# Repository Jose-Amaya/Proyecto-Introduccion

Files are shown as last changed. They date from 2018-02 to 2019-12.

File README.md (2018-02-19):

# Proyecto Introducción a la Ingeniería: Información sobre centrales de generación en Colombia

El proyecto consiste, en una estructura con un mapa de Colombia, el cuál tiene en cada punto donde hay una de las 47 centrales escogidas, un LED, el cuál estará encendido si la central en ese punto se encuentra en funcionamiento, y apagado si la central no está en funcionamiento, el color del LED depende del tipo de generación que se da en la central, y además hay un panel en donde se muestra la información de generación para cada central.

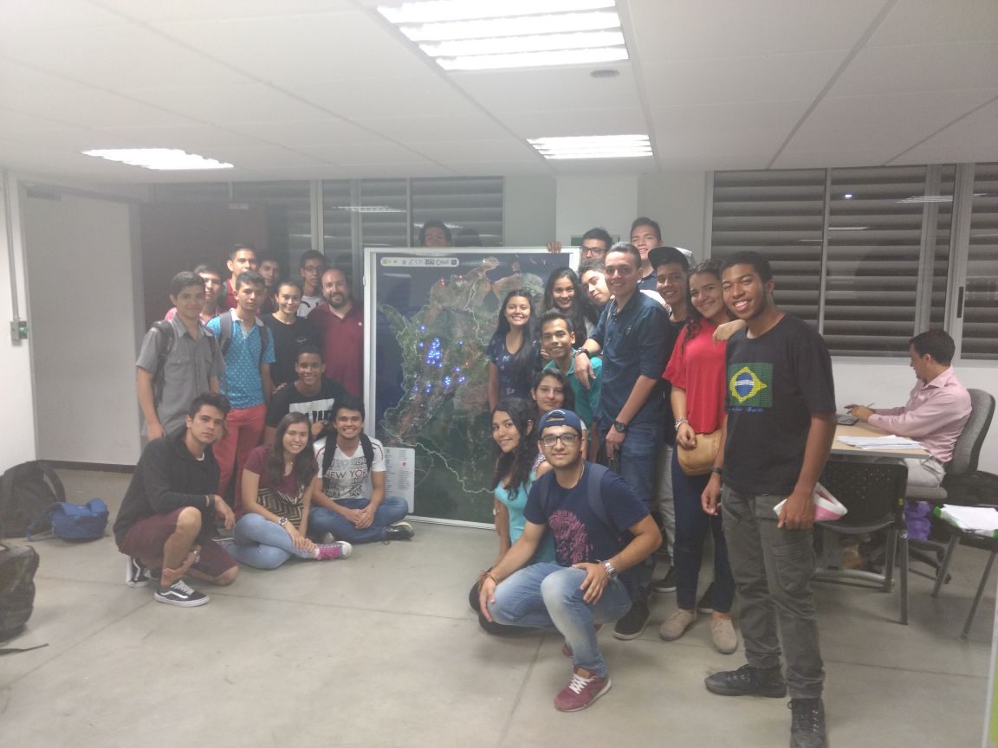
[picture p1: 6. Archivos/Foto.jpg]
Grupo Del Proyecto


# Partes del proyecto

Para el desarrollo del proyecto:
1. Se editó el mapa para agregar la ubicacion de cada central, y las convenciones. [Abrir Carpeta](1.%20Diseño%20mapa/)
2. Se creó un programa en python que corre en una [Raspberri pi 3](https://www.raspberrypi.org/products/raspberry-pi-3-model-b/). [Abrir Carpeta](2.%20Programación/)
3. Se diseño una PCB, para controlar los 47 LEDs, con solo 16 pines ( o menos ) de la raspberry pi ( Por medio de una matriz de LEDS ) [Abrir Carpeta](3.%20PCB/)
4. Se diseño una página web para mostrar los datos de generación de las centrales en un panel. [Abrir Carpeta](4.%20Página%20web/)
5. Se diseño una estructura para contener todos los elementos.
6. Se consiguio información sobre las centrales de xm.com.co [Abrir Archivo Centrales.xlsx](6.%20Archivos/Centrales.xlsx)

Visitar cada carpeta para obtener mas información

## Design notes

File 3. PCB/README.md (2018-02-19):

# Archivos

## Orden de conexion

### tarjetaCentrales

En el archivo se encuentra el diseño de la PCB, y en cada puerto se indica la central a la que corresponde

## PCB

### tarjetaPCB

El diseño de la PCB

### tarjetaSchematic

El esquema del circuito

## EAGLE

Archivos del diseño y esquema para el programa [EAGLE](https://www.autodesk.com/education/free-software/eagle) de Autodesk

## Raspberry Pi

### pi3gpio

Numeración de los pines GPIO de la Raspberry Pi 3

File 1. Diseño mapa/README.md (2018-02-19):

# Diseño del mapa

El mapa se editó en [Adobe Photoshop](https://www.adobe.com/la/products/photoshop.html), agregando iconos a cada punto donde se encontraba una central, y se agregaron convenciones con el listado de centrales

## [Mapa Original](https://correouisedu-my.sharepoint.com/:b:/g/personal/jose2170484_correo_uis_edu_co/EQX8aF4t30xKqxL7ubjEklsB62ActlVU1G1Fpb4uw0_HsA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)

## [Mapa con convenciones](https://correouisedu-my.sharepoint.com/:i:/g/personal/jose2170484_correo_uis_edu_co/EcvZU96U1txIq9gJoRtAlh0BLJq_x_HnzWpGNJGehfyIjA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)

## [Convenciones](https://correouisedu-my.sharepoint.com/:i:/g/personal/jose2170484_correo_uis_edu_co/EULeLKLpBHtKiUwwDA0-71oBcbyABYgxnpovk3rnCAAioA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)

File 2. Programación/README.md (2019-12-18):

# Programación

Los archivos principales se encuentran en la carpeta "project", esta carpeta debe ir en el directorio 'home/pi' de la Raspberry Pi

Se planean utilizar los datos de Despacho Nacional, pero si es necesario, se pueden utilizar los datos de Oferta inicial, para esto se cambia una linea de código en matS.py

# Funcionamiento

Cada script ( *.py ) se encuentra comentado, explicando el funcionamiento de manera detallada

# Requisitos

Una memoria SD, de al menos 8GB, y preferiblemente de clase 10, para el sistema operativo

Para correr los programas en la Raspberry pi 3, Se necesita el sistema operativo [Raspbian (version Jessie)](https://www.raspberrypi.org/downloads/raspbian/), se necesita de [Python3.5](https://www.python.org/downloads/release/python-353/), y tener la [librería Pycurl](http://pycurl.io/) instalada, y para la página web, se necesita del servidor HTTP [Apache](https://httpd.apache.org/download.cgi) y también se necesita del módulo de PHP para el servidor

1. Instalar Raspbian:
	1. Descargar [RASPBIAN STRETCH WITH DESKTOP](https://www.raspberrypi.org/downloads/raspbian/)
	2. Descargar [Etcher](https://etcher.io/)
	3. Seguir las instrucciones de la página de [Etcher](https://etcher.io/) para instalar el sistema operativo en la memoria SD

2. Instalar Python3.5:
	1. Abrir el terminal y ejecutar:
	```
	sudo apt-get install python3.5
	```

3. Instalar la librería Pycurl:
	1. Abrir el terminal y ejecutar:
	```
	sudo pip install pycurl
	```
	2. Si la ejecución falla, ejecutar:
	```
	sudo apt-get install python-pip
	```
		y ejecutar 3.1. denuevo

4. Instalar el servidor HTTP Apache:
	1. Abrir el terminal y ejecutar:
	```
	sudo apt-get install apache2 -y
	```

5. Instalar el módulo PHP:
	1. Abrir el terminal y ejecutar:
	```
	sudo apt-get install php libapache2-mod-php -y
	```

Guias de referencia:
* https://www.raspberrypi.org/documentation/remote-access/web-server/apache.md

## Ejecución

Se ejecutarán matS.py (que actualiza el estado de cada led), dataUpdater.py (que se encarga de correr las funciones para actualizar la información) y dataUpdaterO.py en paralelo. para configurar los programas para que corran al encender la Raspberry, se realizaron estos pasos:

1. Abrir el terminal y ejecutar:
```
sudo nano /lib/systemd/system/matS.service
```

2. Escribir:
```
 [Unit]
 Description=MatS
 After=multi-user.target

 [Service]
 Type=idle
 ExecStart=/usr/bin/python3.5 /home/pi/project/matS.py
 Restart=always
 RestartSec=5

 [Install]
 WantedBy=multi-user.target
```

3. Presionar en orden las teclas / combinaciones de teclas:
```
CTRL + X
Y
ENTER
```

4. Ejecutar:
```
sudo nano /lib/systemd/system/dataUpdater.service
```

5. Escribir:
```
 [Unit]
 Description=DataUpdater
 After=network.target

 [Service]
 Type=idle
 ExecStart=/usr/bin/python3.5 /home/pi/project/data/dataUpdater.py
 Restart=always
 RestartSec=5

 [Install]
 WantedBy=multi-user.target
```

6. Presionar en orden las teclas / combinaciones de teclas:
```
CTRL + X
Y
ENTER
```

7. Ejecutar:
```
sudo nano /lib/systemd/system/dataUpdaterO.service
```

8. Escribir:
```
 [Unit]
 Description=DataUpdaterO
 After=network.target

 [Service]
 Type=idle
 ExecStart=/usr/bin/python3.5 /home/pi/project/data/OfertaInicial(Alternativa)/dataUpdaterO.py
 Restart=always
 RestartSec=5

 [Install]
 WantedBy=multi-user.target
```

9. Presionar en orden las teclas / combinaciones de teclas:
```
CTRL + X
Y
ENTER
```

10. En el terminal ejecutar ( una linea a la vez ):
```
sudo chmod 644 /lib/systemd/system/matS.service
sudo chmod 644 /lib/systemd/system/dataUpdater.service
sudo chmod 644 /lib/systemd/system/dataUpdaterO.service

sudo systemctl daemon-reload

sudo systemctl enable matS.service
sudo systemctl enable dataUpdater.service
sudo systemctl enable dataUpdaterO.service

sudo reboot
```

Guias de referencia:
* https://www.dexterindustries.com/howto/run-a-program-on-your-raspberry-pi-at-startup/#systemd
* https://www.raspberrypi.org/documentation/linux/usage/systemd.md
* https://www.freedesktop.org/software/systemd/man/systemd.service.html

## Información de los archivos

## Project

Es la carpeta que va en /home/pi de la raspberry

### matS.py

Programa que actualiza la matriz de LEDs basado en los datos que se encuentran en ./data/files/matSdata.txt

### infoWeb.py

Programa con una función para actualizar el archivo ./data/files/infoWeb.txt; en cada linea se muestra la informacion de la central para la hora actual, el orden es el mismo que en el archivo Centrales.xlsx (E1, T1 -> T11, H1 -> H35)

### dataUpdater.py

Se encarga de correr las funciones de los diferentes programas en ./data , así se evita que dos programas traten de editar un archivo al mismo tiempo, este programa se corre en paralelo con matS.py

### dataTranslate.py

Se encarga de tomar la información descargada en ./files/downData.txt ; tiene diferentes funciones hechas para acceder mas facilmente a la informacion

## OfertaInicial(Alternativa)

Si se desean usar los datos de Oferta inicial, y no los de Despacho nacional, se corre, de esta carpeta dataUpdaterO.py, y se actualiza matS.py

# PATH

Al pasar a la raspberry pi la carpeta 'project', revisar en los archivos dataGet , dataTranslate , infoWeb y matS, la variable Path al inicio del programa, esta debe ser igual a la carpeta donde se encuentra la carpeta project

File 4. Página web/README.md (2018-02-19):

# Configuración

Para usar la página con el servidor Apache, se requiere reemplazar archivos:

1. Mover la carpeta html a /home/pi

2. Abrir el terminal y ejecutar:
```
sudo rm /var/www/html -r
sudo mv /home/pi/html /var/www
```
## Detalles

La página web usa [Bootstrap framework](https://getbootstrap.com/), las librerías de javascript [jQuery](https://jquery.com/) y [Popper](https://popper.js.org/), y [PHP](http://www.php.net/)

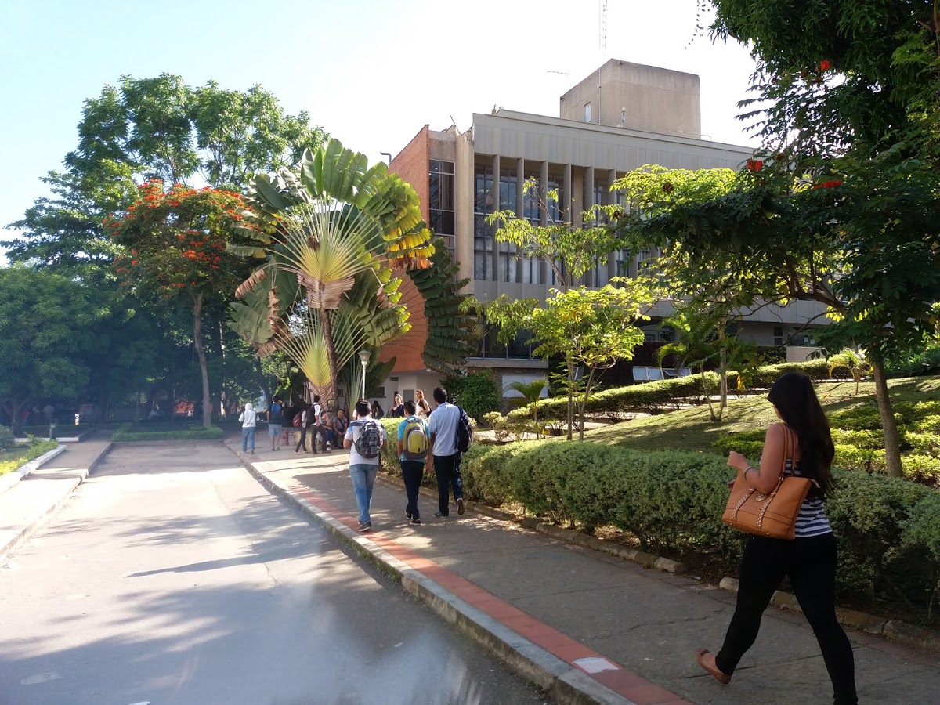
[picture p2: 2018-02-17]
4. Página web/html/img/biblio.jpg

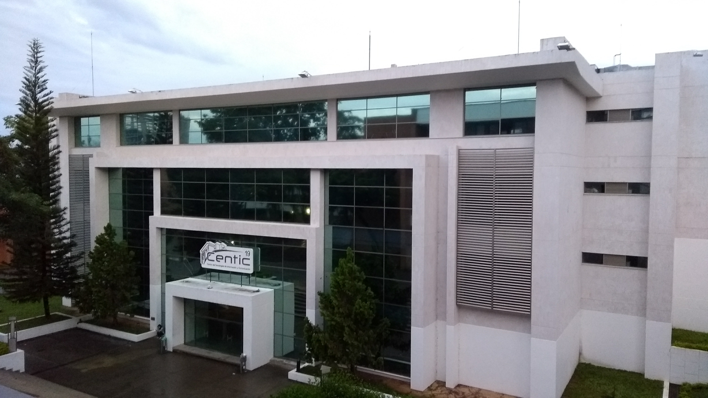
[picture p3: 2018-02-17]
4. Página web/html/img/centic.jpg

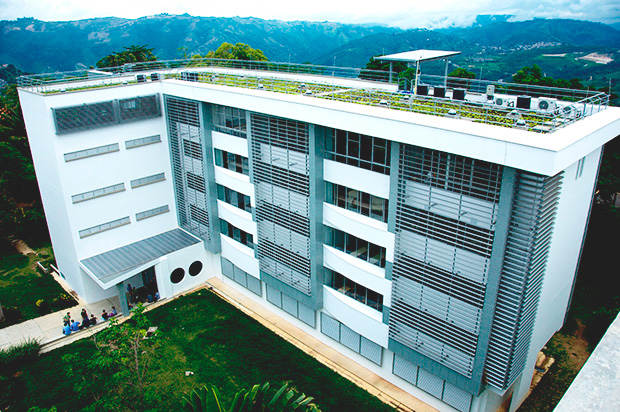
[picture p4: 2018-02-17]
4. Página web/html/img/e3t.jpg

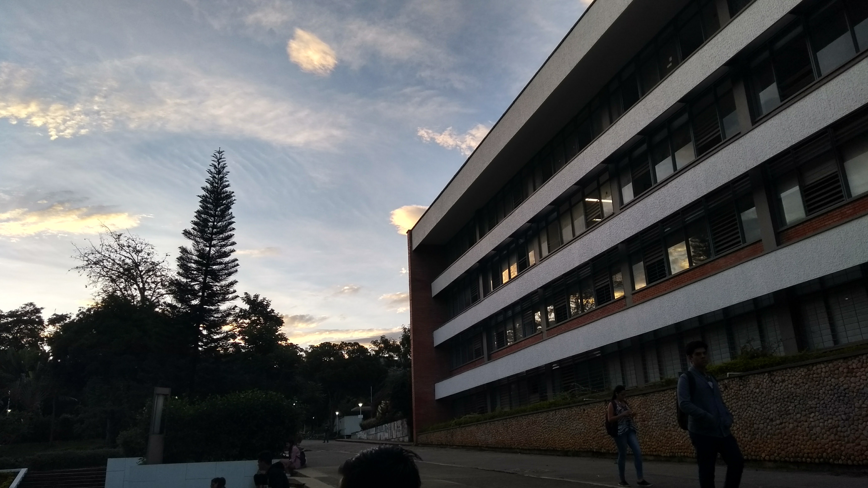
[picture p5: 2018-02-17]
4. Página web/html/img/ct.jpg

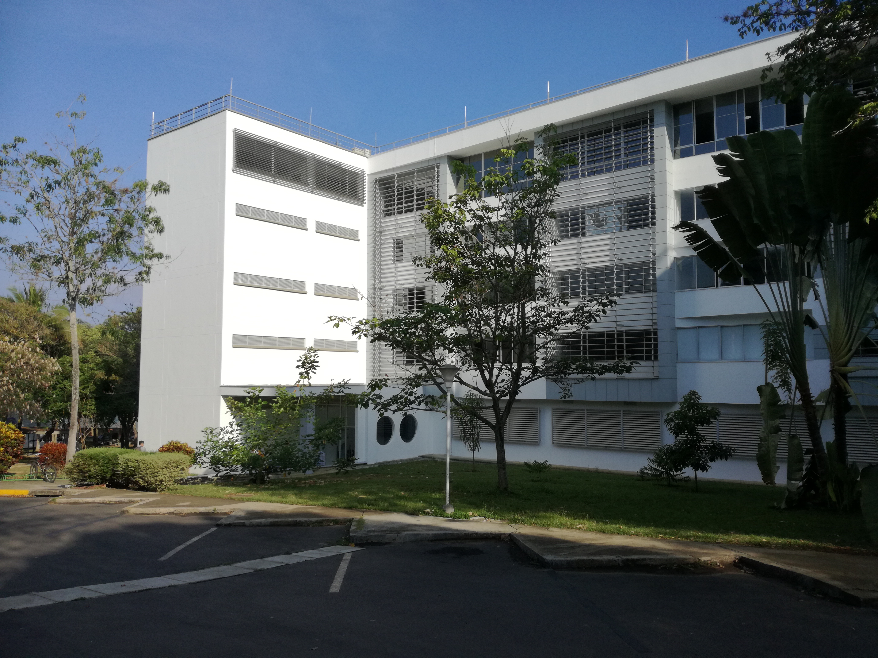
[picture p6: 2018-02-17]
4. Página web/html/img/e3t2.jpg

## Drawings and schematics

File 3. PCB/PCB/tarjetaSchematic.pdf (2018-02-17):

Q9

Q10 | Q11 | Q12 | Q13 | Q14 | Q15 | Q16

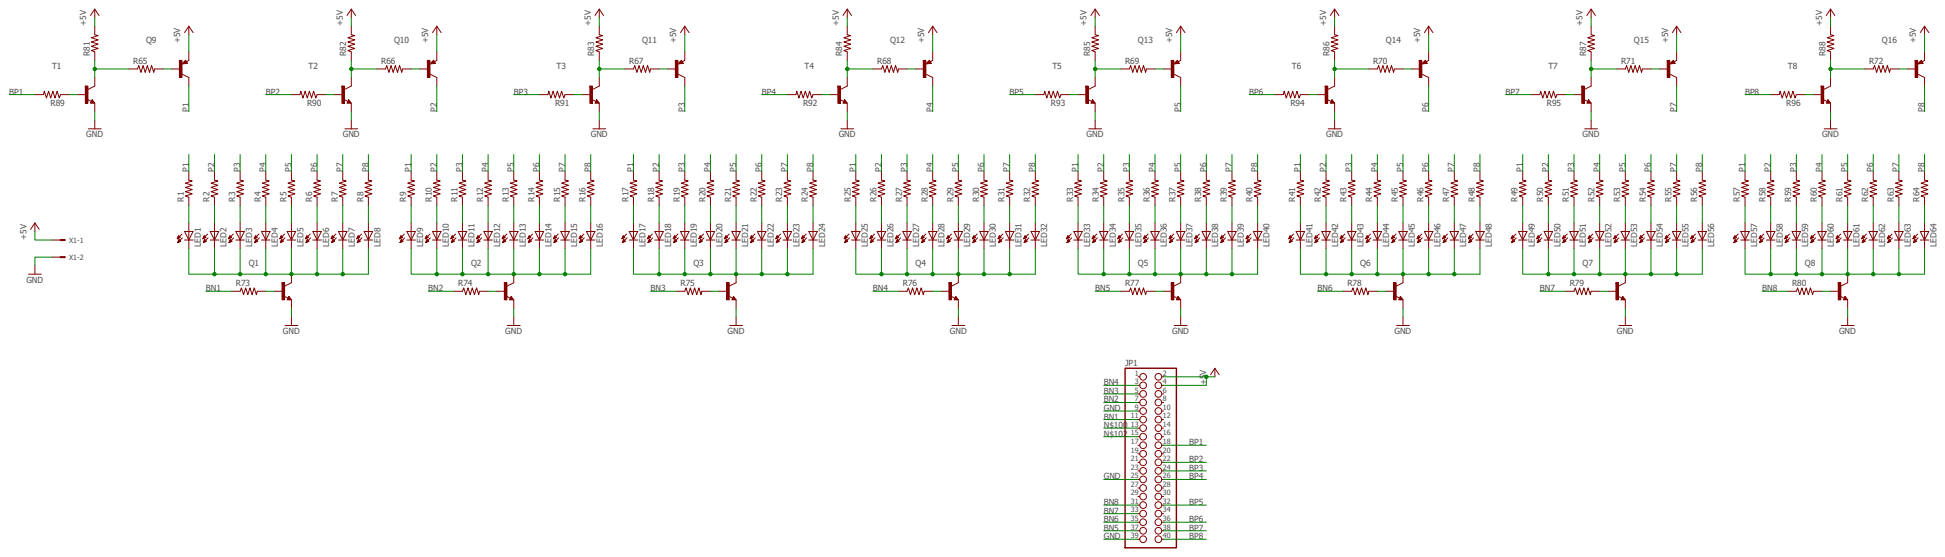
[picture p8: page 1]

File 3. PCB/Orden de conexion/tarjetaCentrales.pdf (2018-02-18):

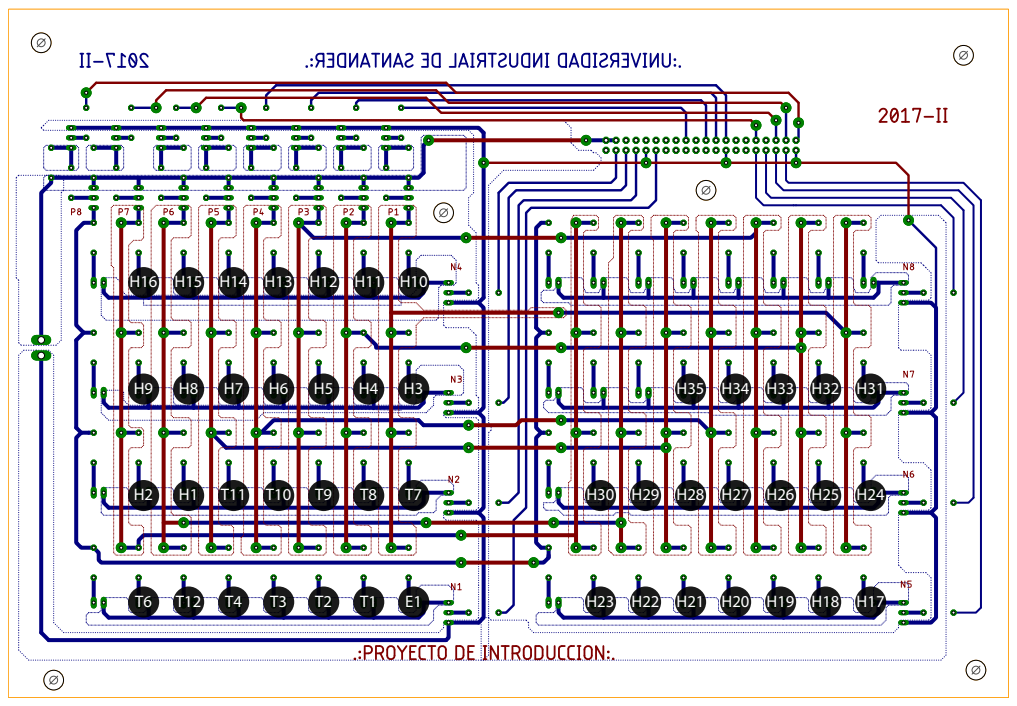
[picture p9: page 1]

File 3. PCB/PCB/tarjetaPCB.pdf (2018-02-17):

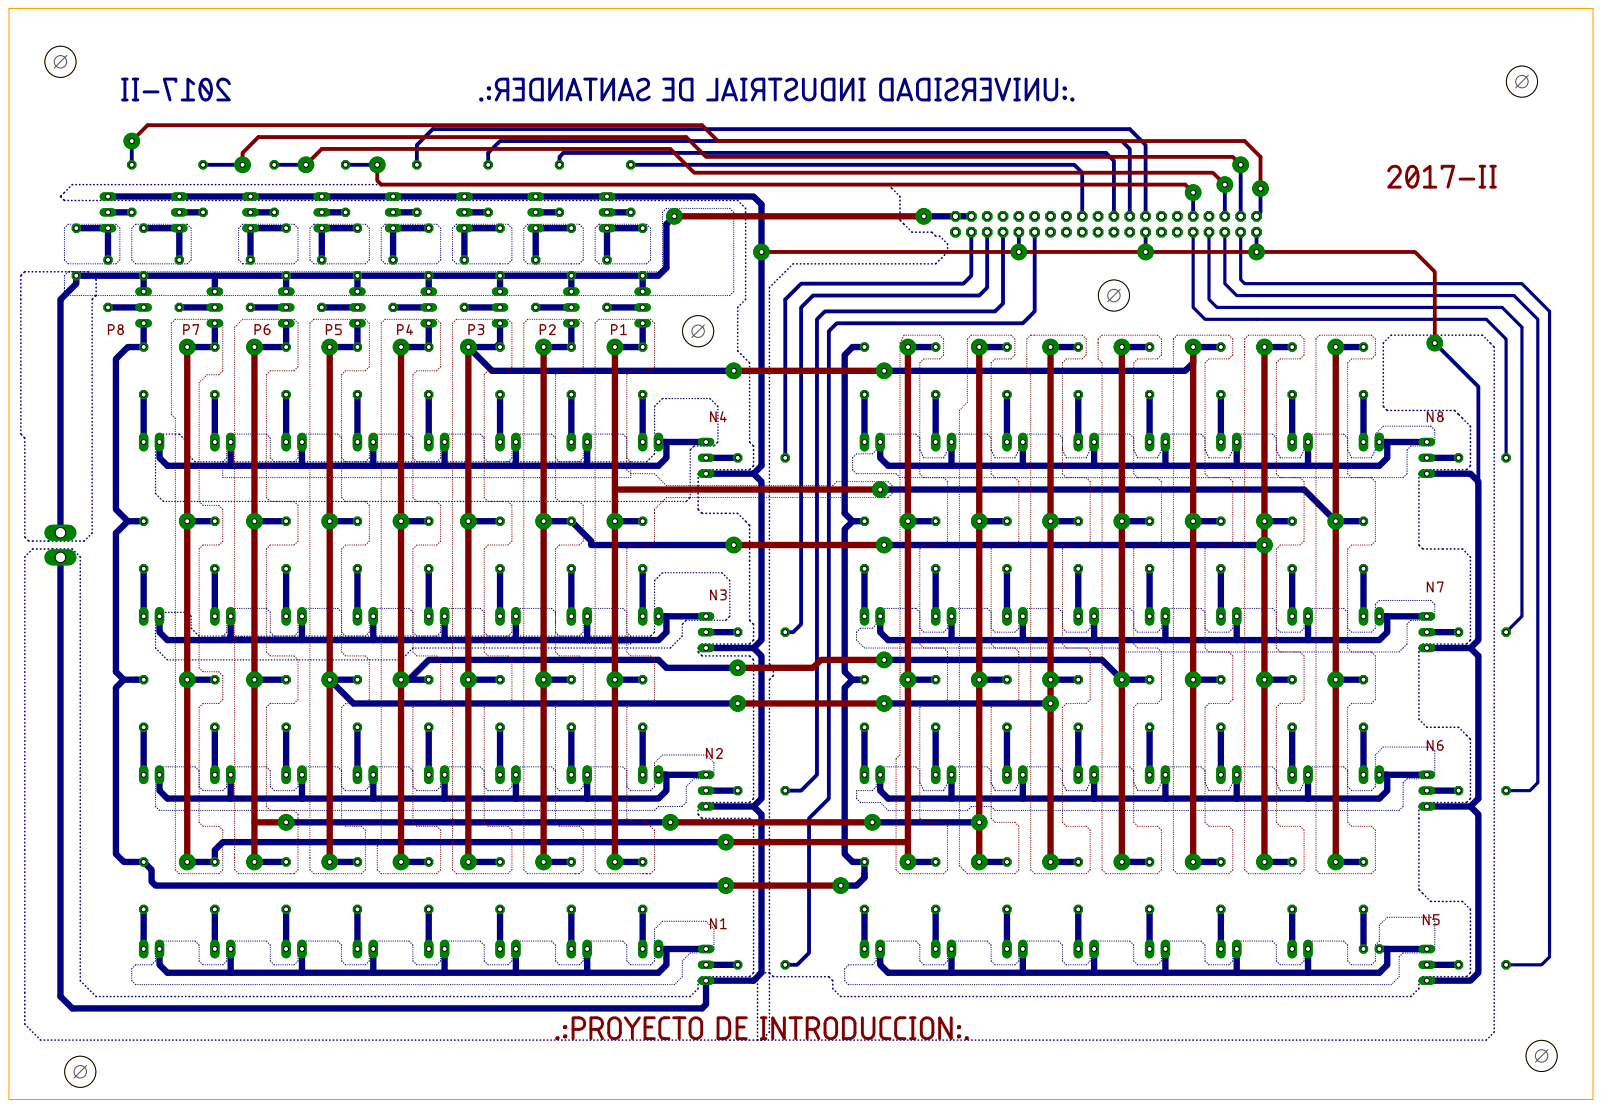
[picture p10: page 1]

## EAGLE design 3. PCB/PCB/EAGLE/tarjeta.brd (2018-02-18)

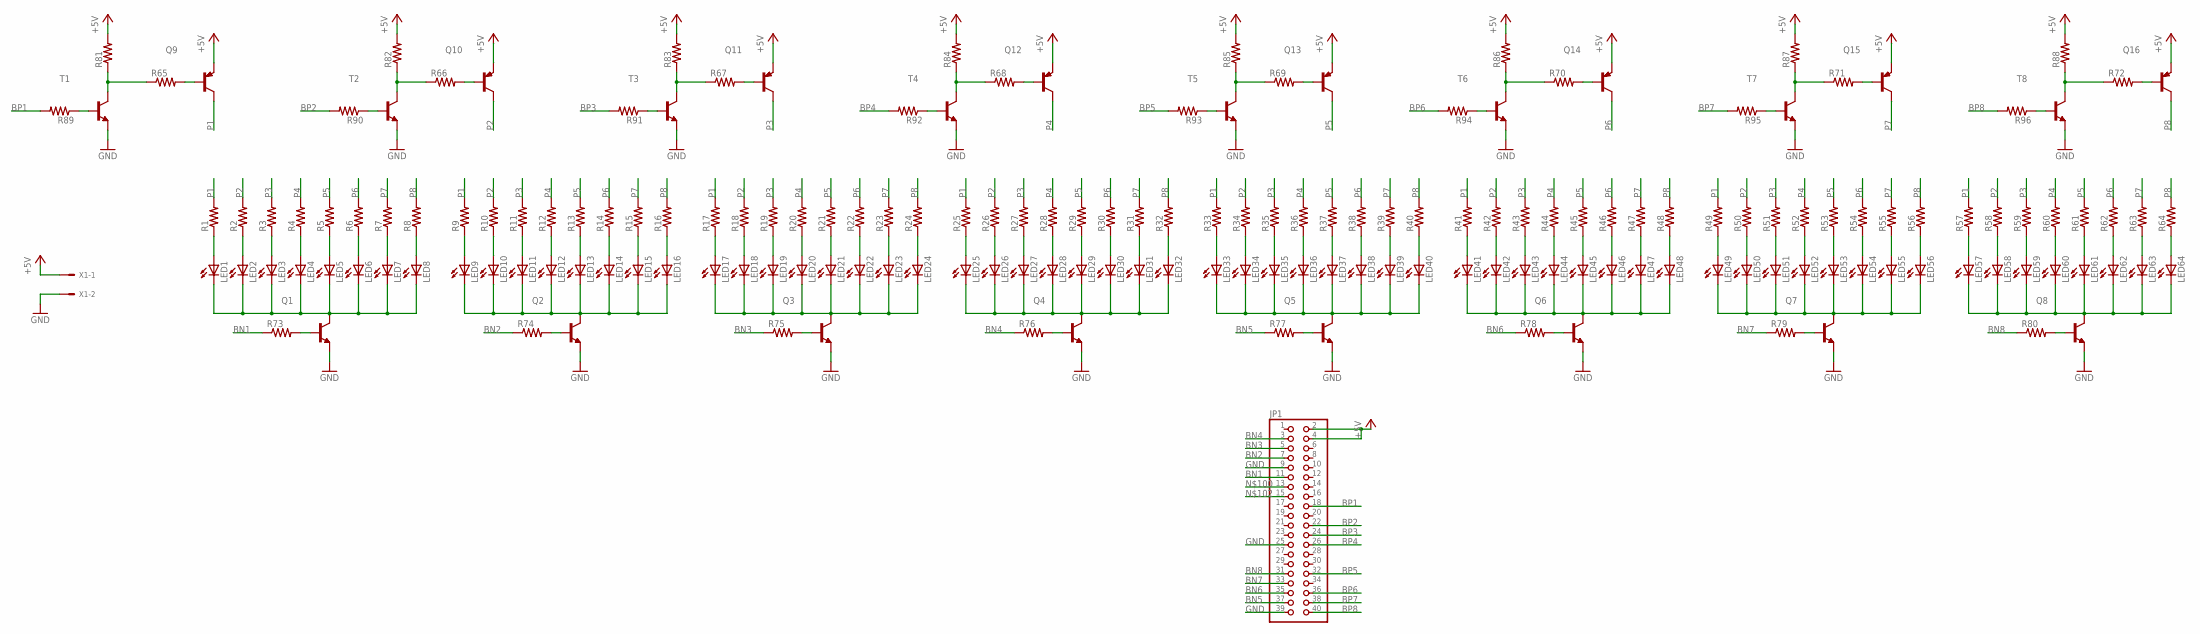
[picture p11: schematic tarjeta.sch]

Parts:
JP1: PINHD-2X20; 2X20
LED1, LED2, LED3, LED4, LED5, LED6, LED7, LED8, LED9, LED10, LED11, LED12, LED13, LED14, LED15, LED16, LED17, LED18, LED19, LED20, LED21, LED22, LED23, LED24, LED25, LED26, LED27, LED28, LED29, LED30, LED31, LED32, LED33, LED34, LED35, LED36, LED37, LED38, LED39, LED40, LED41, LED42, LED43, LED44, LED45, LED46, LED47, LED48, LED49, LED50, LED51, LED52, LED53, LED54, LED55, LED56, LED57, LED58, LED59, LED60, LED61, LED62, LED63, LED64: LED5MM
Q1, Q2, Q3, Q4, Q5, Q6, Q7, Q8: 2N2222TO92-CBE; TO92-CBE
Q9, Q10, Q11, Q12, Q13, Q14, Q15, Q16: 2N2907TO92-CBE; TO92-CBE
R1, R2, R3, R4, R5, R6, R7, R8, R9, R10, R11, R12, R13, R14, R15, R16, R17, R18, R19, R20, R21, R22, R23, R24, R25, R26, R27, R28, R29, R30, R31, R32, R33, R34, R35, R36, R37, R38, R39, R40, R41, R42, R43, R44, R45, R46, R47, R48, R49, R50, R51, R52, R53, R54, R55, R56, R57, R58, R59, R60, R61, R62, R63, R64, R65, R66, R67, R68, R69, R70, R71, R72, R73, R74, R75, R76, R77, R78, R79, R80, R81, R82, R83, R84, R85, R86, R87, R88, R89, R90, R91, R92, R93, R94, R95, R96: R-US_0204/7; 0204/7
T1, T2, T3, T4, T5, T6, T7, T8: 2N3904TO92-CBE; TO92-CBE
X1: KK-156-2

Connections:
+5V: JP1.2, JP1.4, Q9.E, Q10.E, Q11.E, Q12.E, Q13.E, Q14.E, Q15.E, Q16.E, R81.2, R82.2, R83.2, R84.2, R85.2, R86.2, R87.2, R88.2, X1.1
BN1: JP1.11, R73.1
BN2: JP1.7, R74.1
BN3: JP1.5, R75.1
BN4: JP1.3, R76.1
BN5: JP1.37, R77.1
BN6: JP1.35, R78.1
BN7: JP1.33, R79.1
BN8: JP1.31, R80.1
BP1: JP1.18, R89.2
BP2: JP1.22, R90.2
BP3: JP1.24, R91.2
BP4: JP1.26, R92.2
BP5: JP1.32, R93.2
BP6: JP1.36, R94.2
BP7: JP1.38, R95.2
BP8: JP1.40, R96.2
GND: JP1.9, JP1.25, JP1.39, Q1.E, Q2.E, Q3.E, Q4.E, Q5.E, Q6.E, Q7.E, Q8.E, T1.E, T2.E, T3.E, T4.E, T5.E, T6.E, T7.E, T8.E, X1.2
unnamed: LED1.K (C), LED2.K (C), LED3.K (C), LED4.K (C), LED5.K (C), LED6.K (C), LED7.K (C), LED8.K (C), Q1.C
unnamed: LED1.A, R1.1
unnamed: LED2.A, R2.1
unnamed: LED3.A, R3.1
unnamed: LED4.A, R4.1
unnamed: LED5.A, R5.1
unnamed: LED6.A, R6.1
unnamed: LED7.A, R7.1
unnamed: LED8.A, R8.1
unnamed: LED9.K (C), LED10.K (C), LED11.K (C), LED12.K (C), LED13.K (C), LED14.K (C), LED15.K (C), LED16.K (C), Q2.C
unnamed: LED9.A, R9.1
unnamed: LED10.A, R10.1
unnamed: LED11.A, R11.1
unnamed: LED12.A, R12.1
unnamed: LED13.A, R13.1
unnamed: LED14.A, R14.1
unnamed: LED15.A, R15.1
unnamed: LED16.A, R16.1
unnamed: LED17.K (C), LED18.K (C), LED19.K (C), LED20.K (C), LED21.K (C), LED22.K (C), LED23.K (C), LED24.K (C), Q3.C
unnamed: LED17.A, R17.1
unnamed: LED18.A, R18.1
unnamed: LED19.A, R19.1
unnamed: LED20.A, R20.1
unnamed: LED21.A, R21.1
unnamed: LED22.A, R22.1
unnamed: LED23.A, R23.1
unnamed: LED24.A, R24.1
unnamed: LED25.K (C), LED26.K (C), LED27.K (C), LED28.K (C), LED29.K (C), LED30.K (C), LED31.K (C), LED32.K (C), Q4.C
unnamed: LED25.A, R25.1
unnamed: LED26.A, R26.1
unnamed: LED27.A, R27.1
unnamed: LED28.A, R28.1
unnamed: LED29.A, R29.1
unnamed: LED30.A, R30.1
unnamed: LED31.A, R31.1
unnamed: LED32.A, R32.1
unnamed: LED33.K (C), LED34.K (C), LED35.K (C), LED36.K (C), LED37.K (C), LED38.K (C), LED39.K (C), LED40.K (C), Q5.C
unnamed: LED33.A, R33.1
unnamed: LED34.A, R34.1
unnamed: LED35.A, R35.1
unnamed: LED36.A, R36.1
unnamed: LED37.A, R37.1
unnamed: LED38.A, R38.1
unnamed: LED39.A, R39.1
unnamed: LED40.A, R40.1
unnamed: LED41.K (C), LED42.K (C), LED43.K (C), LED44.K (C), LED45.K (C), LED46.K (C), LED47.K (C), LED48.K (C), Q6.C
unnamed: LED41.A, R41.1
unnamed: LED42.A, R42.1
unnamed: LED43.A, R43.1
unnamed: LED44.A, R44.1
unnamed: LED45.A, R45.1
unnamed: LED46.A, R46.1
unnamed: LED47.A, R47.1
unnamed: LED48.A, R48.1
unnamed: LED49.K (C), LED50.K (C), LED51.K (C), LED52.K (C), LED53.K (C), LED54.K (C), LED55.K (C), LED56.K (C), Q7.C
unnamed: LED49.A, R49.1
unnamed: LED50.A, R50.1
unnamed: LED51.A, R51.1
unnamed: LED52.A, R52.1
unnamed: LED53.A, R53.1
unnamed: LED54.A, R54.1
unnamed: LED55.A, R55.1
unnamed: LED56.A, R56.1
unnamed: LED57.K (C), LED58.K (C), LED59.K (C), LED60.K (C), LED61.K (C), LED62.K (C), LED63.K (C), LED64.K (C), Q8.C
unnamed: LED57.A, R57.1
unnamed: LED58.A, R58.1
unnamed: LED59.A, R59.1
unnamed: LED60.A, R60.1
unnamed: LED61.A, R61.1
unnamed: LED62.A, R62.1
unnamed: LED63.A, R63.1
unnamed: LED64.A, R64.1
unnamed: Q9.B, R65.2
unnamed: R65.1, R81.1, T1.C
unnamed: R66.1, R82.1, T2.C
unnamed: Q10.B, R66.2
unnamed: R67.1, R83.1, T3.C
unnamed: Q11.B, R67.2
unnamed: R68.1, R84.1, T4.C
unnamed: Q12.B, R68.2
unnamed: R69.1, R85.1, T5.C
unnamed: Q13.B, R69.2
unnamed: R70.1, R86.1, T6.C
unnamed: Q14.B, R70.2
unnamed: R71.1, R87.1, T7.C
unnamed: Q15.B, R71.2
unnamed: R72.1, R88.1, T8.C
unnamed: Q16.B, R72.2
unnamed: Q8.B, R80.2
unnamed: Q7.B, R79.2
unnamed: Q6.B, R78.2
unnamed: Q5.B, R77.2
unnamed: Q4.B, R76.2
unnamed: Q3.B, R75.2
unnamed: Q2.B, R74.2
unnamed: Q1.B, R73.2
unnamed: R96.1, T8.B
unnamed: R95.1, T7.B
unnamed: R94.1, T6.B
unnamed: R93.1, T5.B
unnamed: R92.1, T4.B
unnamed: R91.1, T3.B
unnamed: R89.1, T1.B
unnamed: R90.1, T2.B
P1: Q9.C, R1.2, R9.2, R17.2, R25.2, R33.2, R41.2, R49.2, R57.2
P2: Q10.C, R2.2, R10.2, R18.2, R26.2, R34.2, R42.2, R50.2, R58.2
P3: Q11.C, R3.2, R11.2, R19.2, R27.2, R35.2, R43.2, R51.2, R59.2
P4: Q12.C, R4.2, R12.2, R20.2, R28.2, R36.2, R44.2, R52.2, R60.2
P5: Q13.C, R5.2, R13.2, R21.2, R29.2, R37.2, R45.2, R53.2, R61.2
P6: Q14.C, R6.2, R14.2, R22.2, R30.2, R38.2, R46.2, R54.2, R62.2
P7: Q15.C, R7.2, R15.2, R23.2, R31.2, R39.2, R47.2, R55.2, R63.2
P8: Q16.C, R8.2, R16.2, R24.2, R32.2, R40.2, R48.2, R56.2, R64.2

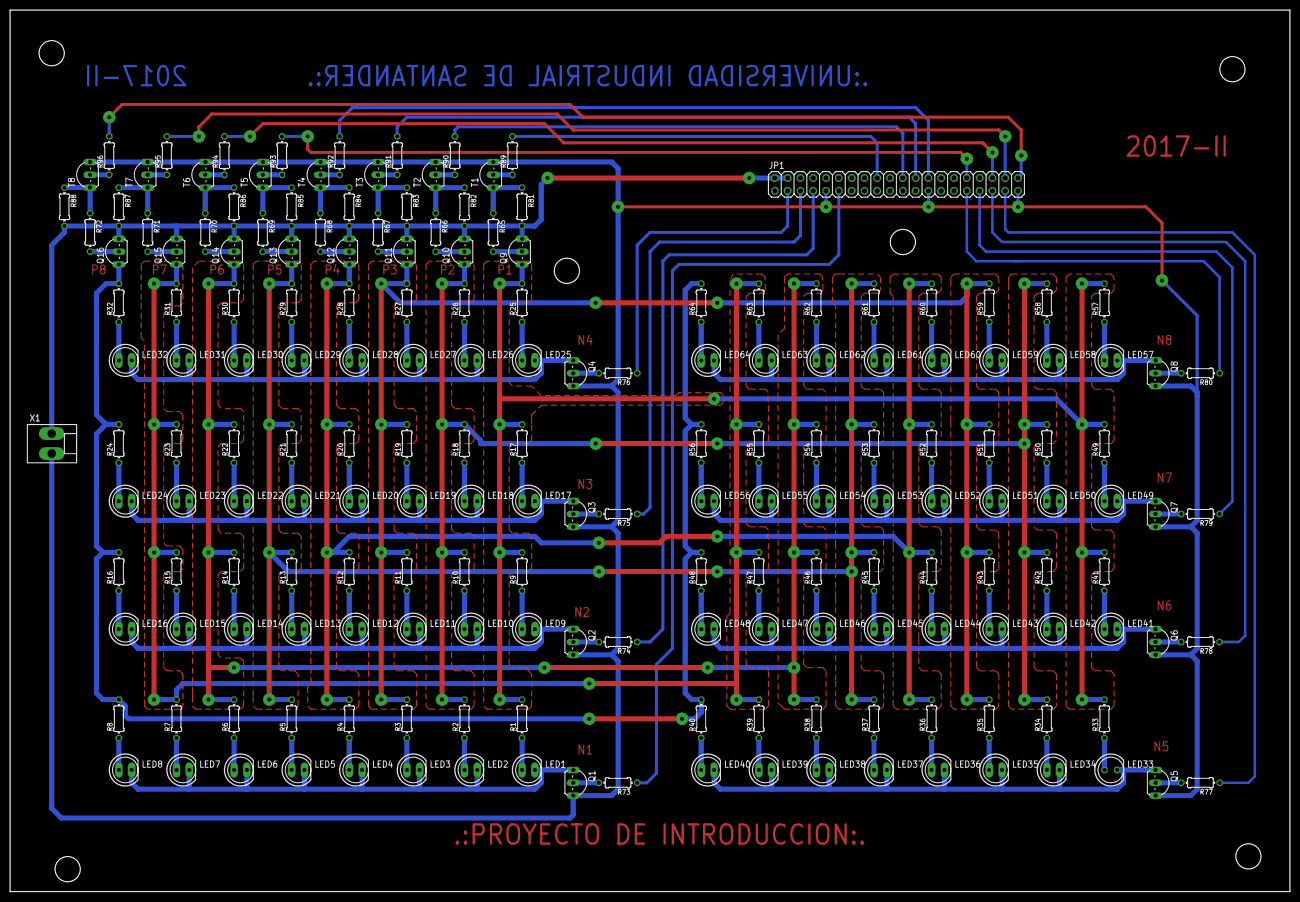
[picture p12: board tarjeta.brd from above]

Board: 2 copper layers, 254.0 x 174.9 mm, 186 parts (0 on the bottom side), 130 nets.

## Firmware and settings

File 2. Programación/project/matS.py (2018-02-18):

## Este programa se corre junto a dataUpdater.py
## Revisar direccion path
path = "/home/pi/project/data/files/" ## direccion al archivo files, si la carpeta project se encuentra en /home/pi

# Importar librerias necesarias para el funcionamiento
import RPi.GPIO as GPIO ## Se importa la libreria RPi.GPIO, y se le da el nombre de GPIO para que sea de mas facil acceso (para llamar una funcion de la liberia se usara GPIO.funcion en vez de RPi.GPIO.funcion) esta libreria permite controlar la funcion y el estado de los pines de la raspbery (mirar 3.PCB/Raspberry Pi/pi3gpio.png)
import time ## Libreria usada para hacer que el programa se pause por un tiempo especifico (usando la funcion sleep de la libreria ( time.sleep(tiempo en segundos) ))
import ast ## Libreria usada para transformar el tipo de informacion que se obtiene del archivo de texto evaluandolo; este tipo es "string" o cadena; y se necesita una variable de tipo lista (o matriz) ( ast.literal_eval(string a evaluar) )

GPIO.setmode(GPIO.BOARD) ## Hay varias maneras de numerar los pines de la raspberry, aca se define el tipo de numeracion que se va a usar

wt = 0.001 ## Una variable que representa el tiempo que una fila de leds va a estar prendida

global matrix ## Definicion de la variable global matrix, la cual tendra la informacion de que leds tienen que estar encendidos
matrix = [[0]*8 for x in range(0,8)] ## Se crea una matriz 8x8 de ceros (una lista, compuesta por 8 listas, compuestas cada una por 8 ceros)

column = [18, 22, 24, 26, 32, 36, 38, 40] # Lista de los pines que van conectados a la PCB, 'BP1' -> 'BP8' ('P1' -> 'P8' Esquema PCB)
row = [11, 7, 5, 3, 37, 35, 33, 31] # Lista de los pines que van conectados a la PCB, 'BN1' -> 'BN8' (Esquema PCB)

## Configurar los pines column y row como salidas
for i in row:
    GPIO.setup(i, GPIO.OUT) ## Para cada elemento de la lista row (es decir, el numero de un pin) configurarlo como salida
for x in column:
    GPIO.setup(x, GPIO.OUT) ## Para cada elemento de la lista column (es decir, el numero de un pin) configurarlo como salida

try: # Para manejo de errores, se trata de ejecutar esta parte del codigo, si sucede el evento descrito despues de 'except', se ejecuta otra parte del codigo, y al cerrar el programa manualmente, se ejecuta la parte de codigo despues de 'finally'

## Definicion de una funcion, llamada allofon ( todos apagados ) , que no toma argumentos, y cambia el estado de todos los pines en las listas row y column, como low/0/apagado (Apaga todos los leds)
    def allofon():
        for i in row: # Para cada elemento de la lista row (Pines de la raspberry, conectados a 'BP8' -> 'BP1')
            GPIO.output(i, False) # Definir el estado del pin como low/0/apagado
        for x in column: # Para cada elemento de la lista column (Pines de la raspberry, conectados a 'BN1' -> 'BN8')
            GPIO.output(x, False) # Definir el estado del pin como low/0/apagado

## Definicion de una funcion, llamada updateleds ( actualizar leds ), la cual actualiza el estado de los leds, la cual prende y apaga los leds de manera rapida, para esto, se miran los datos de cada fila, si se necesita encender un led en una fila, se enciende la fila y los leds, despues se esperan 'wt' segundos, se apagan todos los leds, y se continua con las siguientes filas
    def updateleds(): ## Configurar el estado de los pines

        for x in range(0,8): ## Ciclo for, que se ejecuta 8 veces ( range(0,8) es una lista de 8 elementos, los numeros de 0 a 7 ), este ciclo servira para acceder a cada fila de 'matrix' ( Cada fila de 'matrix' representa un pin conectado a un 'BN' de la PCB, esta lista contiene 8 elementos, cada uno, un uno o un cero, que corresponden al estado de cada pin 'P' en la fila respectiva )
                if 1 in matrix[x]: ## Si se necesita encender al menos un led en la lista numero x de 'matrix' ( Es decir si se encuentra un 1, ya que si para la fila x, no hay leds por encender, los elementos de la lista seran ceros ), encender el pin correspondiente a la fila x
                    GPIO.output(row[x], True) ## (Ej: Si la fila 1 ( matrix[0] ) contiene un 1, encender pin correspondiente a la fila 1 , es decir, BN1, que es el primer elemento de 'row' ( row[0] ))
                    for i in range(0,7): ## En la PCB, hay 7 columnas ( 'P8' ( column[7] ) no tiene leds conectados ), este ciclo for servira para acceder a cada valor de la lista 'matrix[x]' ( Ej: El elemento 2 de la fila 1 ( LED conectado con la Fila 'BN1', Columna 'P2' ) matrix[0][1] )
                        if matrix[x][i] == 1: ## Se miran cuales leds de la fila se necesitan encender
                            GPIO.output(column[i], True) ## Si se necesita encender un led en la columna i, encender el pin correspondiente a la columna ( estado high/1/encendido )
                    w() ## funcion para esperar 'wt' segundos ( definida despues )
                    allofon() ## Apagar todos los leds, para despues continuar con la siguiente fila

## Definicion de la funcion from88to87mat  ( de una matriz 8*8 a una matriz 8*7 ), que toma de argumentos una matrix 8*8 y devuelve una matriz 8*7 ( 8 filas, 7 columnas ) ( los ultimos elementos de 'matrix' se ignoran , ya que solo se muestra informacion sobre 47 centrales )
    def from88to87mat(mat):
        longMat = [] ## definicion de una matriz sin elementos
        for x in range(0,8): # Ciclo for que se ejecuta 8 veces, cada vez tomando un numero en orden de 0 -> 8
            for y in range(0,8): # Ciclo for que se ejecuta 8 veces, cada vez tomando un numero en orden de 0 -> 8
                longMat.append(mat[x][y]) # Agregar a la matriz longMat, el elemento mat[x][y] de la matriz ( Estos dos ciclos for, acceden a cada elemento de la matriz 'mat' ( que al ejecutar la funcion sera 'matrix' ) y lo añaden a la lista longMat )
                ## Al ejecutarse los ciclos for, la matriz 'longMat' es una lista de 64 elementos, con los datos de 'mat'

        the87mat = [] ## definicion de matriz sin elementos, esta sera la matriz que devuelva la funcion

        for x in range(0,8): # Ciclo for que se ejecuta 8 veces ( Una vez por cada fila )

            phmat = [] ## lista placeholder, para guardar datos temporalmente en el ciclo for, la 'fila' x de longMat ( un grupo de 7 elementos )

            for y in range(0,7): # Ciclo for que se ejecuta 7 veces ( Una vez por cada columna )
                phmat.append(longMat[y+x*7]) ## Tomar el elemento numero y + x*7 ( longMat tiene 64 elementos , si se mira como una matriz 7*8, cada grupo de 7 elementos es una fila, con la expresion y + x*7 se accederia al elemento 'y' de la fila 'x' )

            the87mat.append(phmat) ## Agregar la lista phmat a la matriz the87mat

        return the87mat ## devolver la matriz 8*7
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

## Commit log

2017-12-13 Arreglo de errores
2017-12-13 Arreglo de errores y mejora de funciones
    [Centrales (Con oferta inicial).xlsx, Centrales (Sin oferta inicial).xlsx]
2017-12-14 Se agrego codigo, con los pines para utilizar los programas con la PCB (Antes se usaban pines arbitrarios)
